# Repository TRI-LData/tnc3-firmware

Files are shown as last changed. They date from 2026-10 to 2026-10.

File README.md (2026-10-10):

# TNC3L
# !!! THIS RESPOSITORY IS WORK INPROGRESS !!!
## Current Status: Repository work and TNC3L prep for FCC testing

TNC3L was developed as an enhanced hardware version of Mobilinkd’s open-sourced TNC3.  
The goal was to make TNC3L easier to use and maintain from a hardware perspective and 
not to change/rewrite firmware developed for TNC3.  This would ensure application compatibility, 
including TNC3 firmware updates.  TNC3L is open-sourced and licensed under GPL-3.0.  This 
repository is a fork of 

 [Mobilinkd TNC3 Repository](https://github.com/mobilinkd/tnc3-firmware)

 TNC3L hardware specific files are in the TNC3L repository directory.  PCB files,
 schematics, BOM, and 3D printer STL files are included.

## TNC3L and TNC3 Differences

TNC3L firmware is almost identical to TNC3 firmware as posted on GitHub.  Minor firmware
changes have been made to accommodate hardware differences.  Functionally all applications 
compatible with the TNC3 should work with the TNC3L.  This repository is for TNC3 firmware
ported to TNC3L hardware.  The code changes are enabled with a define statement
in main.h, #define TNC3L.

TNC3L modified files from TNC3 are:
1) main.h
2) main.c
3) util.h (new)
4) LEDIndicator.cpp
5) IOEventTask.cpp
Search for #ifdef TNC3 in each to view modifications.

TNC3L was designed to be attached to an HT by simply plugging it in.  There are no 
cables or need to attach the device to the HT with rubber bands or Velcro.   Simply plug 
it in or out of the HT’s speaker and mic jacks.  This configuration allows the HT 
to be comfortably handheld, used with a belt clip, or inserted in the charging 
cradle without detaching the TNC3L from the HT.  Power button and status indicators
are visible and accessible from the front of the HT.

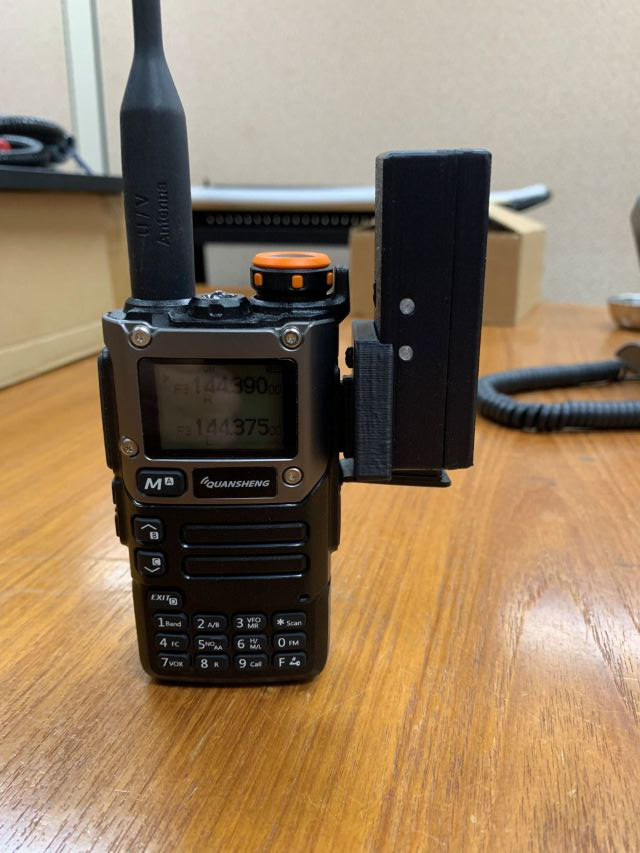
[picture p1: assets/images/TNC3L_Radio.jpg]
TNC3L attached to HT

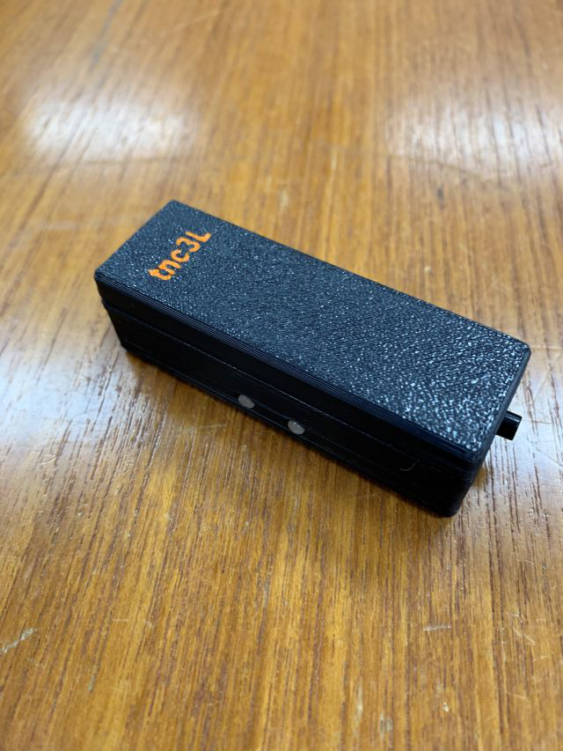
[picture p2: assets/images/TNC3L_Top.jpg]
TNC3L Top

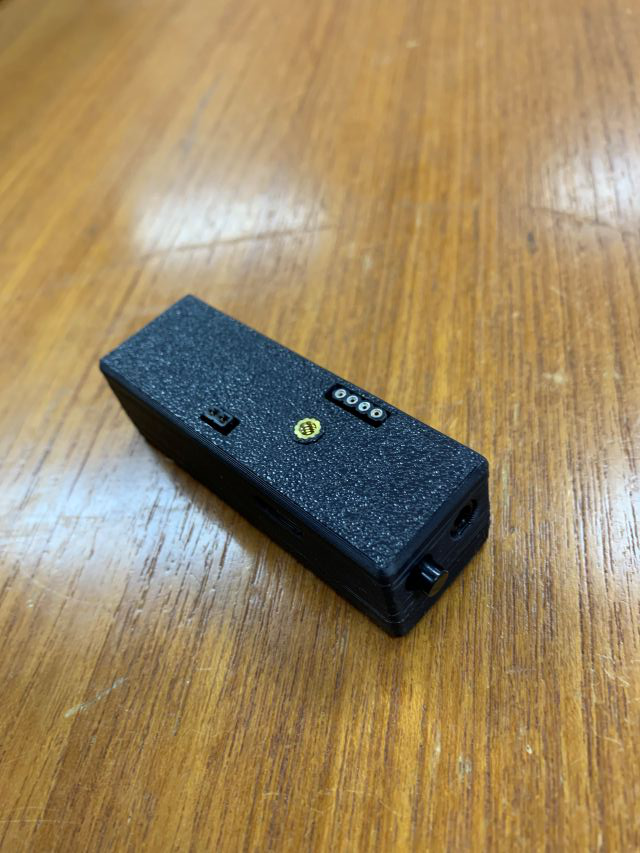
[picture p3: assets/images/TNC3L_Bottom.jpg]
TNC3L Bottom


### Rechargeable/Replaceable Battery
TNC3L uses a standard 14500 lithium Ion 3.7V battery.  Battery protection and
charging are provided on the circuit board.  Discharged batteries can be replaced without tools or 
charged via the USB port.  The TNC3L circuit board can accommodate other batteries 
size with higher capacities.   However, the standard enclosure is designed for 
14500 batteries only.

### Power button
The push button located on the base of the TNC3L is used to power on and off the device.  
In the off position it disconnects the battery from other circuitry.  The MCU, Bluetooth module, 
LEDs, etc. do not consume any power in the off position.  It is a latching push button switch.  
The on or off position is clearly visible.  Powering the device directly with a push button 
eliminated the need for the MCU to be “on” to control power to other devices and to detect 
button presses to turn itself on or off.  This approach maximizes battery life.  
However, minor firmware modifications were needed.

### USB Type C Connector
A type C USB connector is used instead of a micro-USB.  It has the same connectivity as TNC3
and can be used for charging or programming.  Power is always on when the USB is plugged in
irrespective of the push button.

### Status Indicators (LEDs)
Two status indicators are on the TNC3L.  One is the same as TNC3 for radio, Bluetooth status 
and processor status.  The other is for battery charging.  TNC3L has three charging 
states; green for charging complete; red for charging; off if no USB or off if the USB 
is plugged in and there is a charging error.

### DFU MODE PINS
TNC3L uses a two-pin IDC header to place it into DFU mode for programming.  It does not have 
separate reset or DFU buttons.   
1) Power button in the off position
2) Short the IDC header (jumper wire)
3) Attach USB
4) Remove jumper

### Radio to TNC3L Interface
A TRRS 3.5mm jack and a 4 pin IDC header are available to interface the TNC3L to a radio.  
The 3.5mm TRRS jack has the same signals as the TNC3.  Cables compatible with TNC3 should also be 
compatible with TNC3L.  A second MIC/speaker interface was added to the TNC3L using 
a 4-pin IDC connector.  This port can be used for connecting the TNC3L to radios without
using a 3.5mm plug.  TNC3L K1 style docking adapter is an example.  It connects the TNC3L to the HT without a cable.

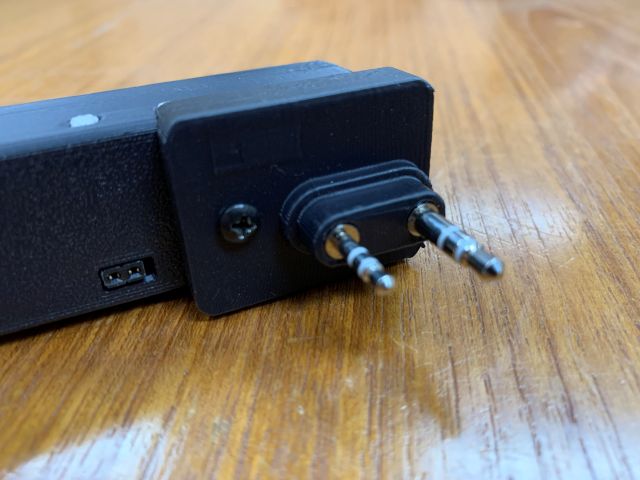
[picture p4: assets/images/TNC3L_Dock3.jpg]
TNC3L DOCK3


### 3D Printed Enclosure
The TNC3L enclosure and docking adapter are made from 3D printed parts.  FCC testing was
also performed using TNC3L as shown here.  TNC3L is not limited to the a specific enclosure.  Users are welcome to 
design custom enclosures to adopt various battery sizes and device orientation. 
 
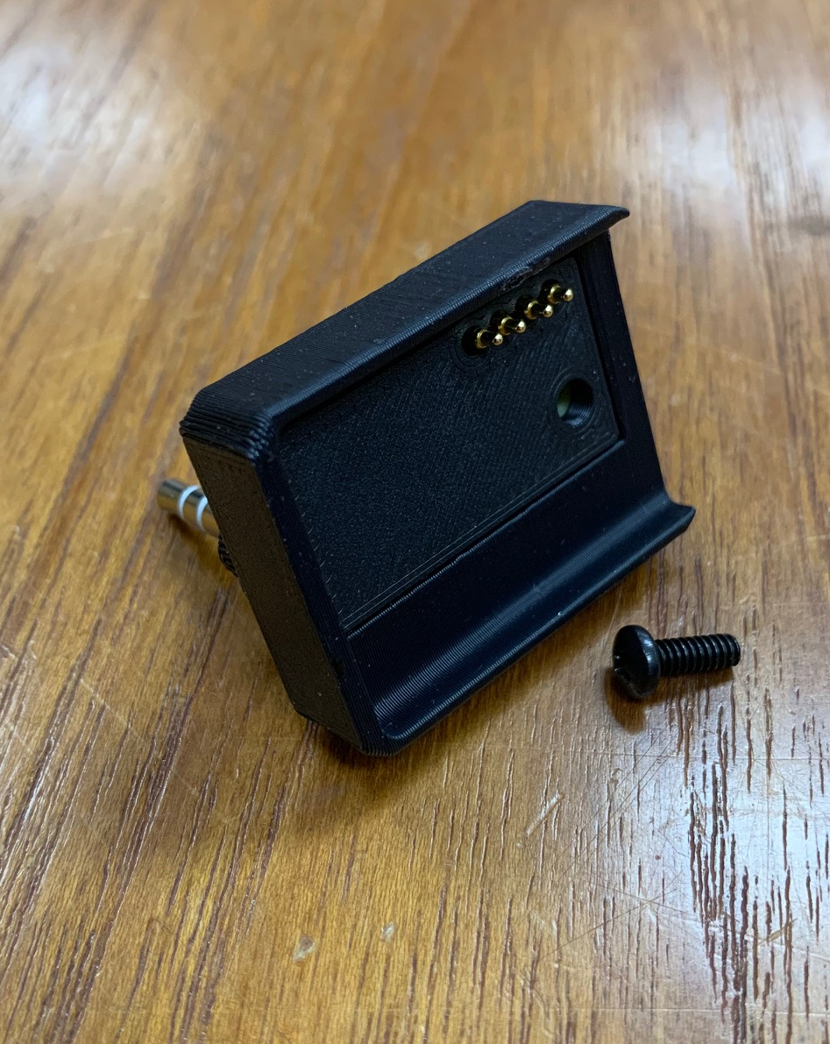
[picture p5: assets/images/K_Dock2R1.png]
K Dock


# Firmware 
Please refer to Mobilinkd's TNC3 GitHub repository for building and installing firmware.  Do not use frimware
directly from their repository, use the firmware source provided in this repository.

 [Mobilinkd TNC3 Repository](https://github.com/mobilinkd/tnc3-firmware)

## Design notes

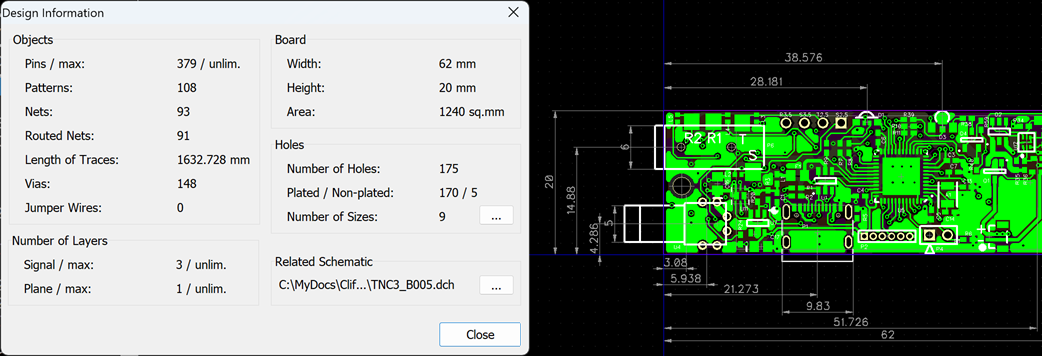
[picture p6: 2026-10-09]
TNC3L_Hardware/TNC3L_Info/TNC3L_B005_Info.png

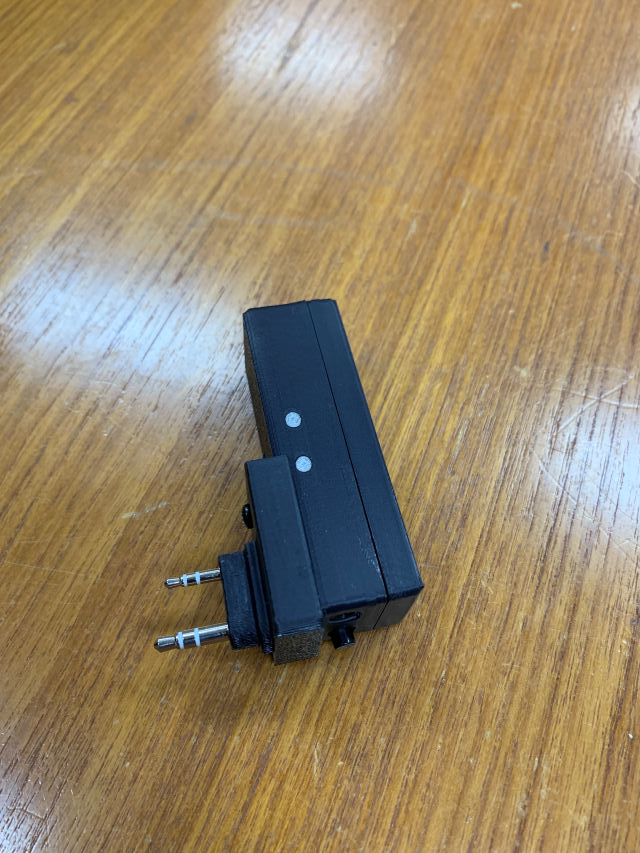
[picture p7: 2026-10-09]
assets/images/TNC3L_Status.jpg

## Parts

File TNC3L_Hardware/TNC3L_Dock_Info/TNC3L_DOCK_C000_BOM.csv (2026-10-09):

# | RefDes | Value | Name | Pattern | Quantity
1 | J1 | 2.5 R | J0806 | J0604 | 1
2 | J2 | 3.5 T | J0806 | J0604 | 1
3 | P1 | IDC1X4 | 6mm Pogo | TNC3_POGO | 1
4 | P2 | 2.5 TR | IDC1X2 | IDC1X2 | 1
5 | P3 | 3.5 SR | IDC1X2 | IDC1X2 | 1
6 | P4 | IDC1X2 | IDC1X2 | IDC1X2 | 1

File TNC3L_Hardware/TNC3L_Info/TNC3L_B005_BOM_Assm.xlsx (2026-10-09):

 | TNC3L_B005_BOM |  |  |  |  |  | NO POP = do not install
Item | RefDes | Value | Name | Pattern | Quantity | Distributor | Comment
1 | A1 | 32.768KHz | ABS07L-32.768KHZ-T | ABS07L | 1 | Digikey
2 | B1 | DF52-2S | DF52-2S-0.8H(21) | DF52-2S | 1 | Digikey
3 | C1, C24, C25 | 4.7uF 10V | CL05A475MP5NRNC | CAP_0402 | 3 | Digikey
4 | C2, C18 | 10nF | GRM155R71C103KA01D | CAP_0402 | 2 | Digikey
5 | C3, C4, C5, C6, C7, C8, C9, C11, C22, C27, C30, C32 | 0.1uF | CL05B104KO5NNNC | CAP_0402 | 12 | Digikey
6 | C10, C20 | 1nF | GRM155R71C102KA01D | CAP_0402 | 2 | Digikey
7 | C12, C21 | 33nF | GRM155R61C333KA01D | CAP_0402 | 2 | Digikey
8 | C13, C14 | 22pF | CC0402JRNPO7BN220 | RES_0402 | 2 | Digikey
9 | C15, C23 | 470pF | CC0402JRNPO7BN471 | CAP_0402 | 2 | Digikey
10 | C16, C17 | 10uF 16V | CL21A106KOCLRNC | CAP_0805 | 2 | Digikey
11 | C19 | 2.2uF | CC0402KRX5R7BB225 | CAP_0402 | 1 | Digikey
12 | C26 | .22uF | CL05B224KO5NNNC | CAP_0402 | 1 | Digikey
13 | C28 | 33uF 6.3V | GMC21X5R336M6R3NT | CAP_0805 | 1 | Digikey
14 | C29 | 1uF 16V | CL05A105KO5NNNC | RES_0402 | 1 | Digikey
15 | C31 | 100pF 16V | C0402C101K4RACAUTO | RES_0402 | 1 | Digikey
16 | D1 | RGB_CA | E3113BGR-10D0003Q3U1930 | LED_RGB_RA_SM | 1 | Digikey
17 | D2 | PMEG2010ER | PMEG2010ER | SOD-123F | 1 | Digikey
18 | D3 | B2592USNG20D0001L2U1930 | LED_RG | LED_RG_B2592USNG20D0001L2U1930 | 1 | Digikey
19 | D4 | BAT54SWT1G | BAT54SWT1G_SOT323 | SOT323 | 1 | Digikey
20 | D5 | 4.3V Zener | BZT52C4V3LP-7 | DIO_0402 | 1 | Digikey
21 | F1 | 750mA | PTS08056V075 | RES_0805 | 1 | Digikey
22 | L1 | FB 600R@100Mhz | BLM15AX601SN1D | RES_0402 | 1 | Digikey
23 | L2, L3, L4, L5 | BLM15AG102SN1D | BLM15AG102SN1D | IND_0402 | 4 | Digikey
24 | L6 | MU1608-221Y | MU1608-221Y | IND_0603 | 1 | Digikey
25 | P1 | USB-C | USB4105-GF-A | USB4105_GCT | 1 | Digikey
26 | P2 | IDC1X6 | IDC1x6 | IDC1X6_05 | 1 |  | NO POP
27 | P3 | IDC1X4 | IDC1X4_05 | IDC1X4_Socket | 1 |  | NO POP
28 | P4 | IDC1X2 | IDC1X2 | IDC1X2 | 1 |  | NO POP
29 | P6 | TRRS 3.5 | SJ2-3574A-SMT-TR | SJ2-3574A-SMT-TR | 1 | Digikey
30 | Q1 | DMP3099L-7 | MOSFET-P | SOT23 | 1 | Mouser
31 | Q2 | FS8205A | FS8205A-SOT23-6 | SOT23-6 | 1 | Digikey
32 | Q4 | MMBT2222A | NPN | SOT23 | 1 | Digikey
33 | R1, R38, R39, R41 | 1.5K | 1.5K | RES_0402 | 4 | Digikey | Generic, 1%, 1/10 W or better
34 | R2, R5 | 5.1K | 5.1K | RES_0402 | 2 | Digikey | Generic, 1%, 1/10 W or better
35 | R3, R13, R28 | 30K | 30K | RES_0402 | 3 | Digikey | Generic, 1%, 1/10 W or better
36 | R4 | 0 | 0 | RES_0402 | 1 | Digikey | Generic, 1%, 1/10 W or better
37 | R6, R20, R32 | 10K | 10K | RES_0402 | 3 | Digikey | Generic, 1%, 1/10 W or better
38 | R7, R8, R9 | 220 | 2.2K | RES_0402 | 3 | Digikey | Generic, 1%, 1/10 W or better
39 | R10, R11, R24 | 4.7K | 4.7K | RES_0402 | 3 | Digikey | Generic, 1%, 1/10 W or better
40 | R12, R30, R31 | 2.2K | 2.2K | RES_0402 | 3 | Digikey | Generic, 1%, 1/10 W or better
41 | R14, R26 | 16K | 16K | RES_0402 | 2 | Digikey | Generic, 1%, 1/10 W or better
42 | R15, R17 | 220 | 220 | RES_0402 | 2 | Digikey | Generic, 1%, 1/10 W or better
43 | R16, R19, R25 | 100K | 100K | RES_0402 | 3 | Digikey | Generic, 1%, 1/10 W or better
44 | R18, R23 | 510 | 510 | RES_0402 | 2 | Digikey | Generic, 1%, 1/10 W or better
45 | R21, R22 | 470 | 470 | RES_0402 | 2 | Digikey | Generic, 1%, 1/10 W or better
46 | R27 | 6.8K | 6.8K | RES_0402 | 1 | Digikey | Generic, 1%, 1/10 W or better
47 | R29 | 100 | 100 | RES_0402 | 1 | Digikey | Generic, 1%, 1/10 W or better
48 | R33 | 0 | RC0603JR-070RL | RES_0603 | 1 | Digikey | Generic, 1%, 1/10 W or better
49 | R34 | 2K | 2k | RES_0402 | 1 | Digikey | Generic, 1%, 1/10 W or better
50 | R35 | 20 | 20 | RES_0402 | 1 | Digikey | Generic, 1%, 1/10 W or better
51 | R36 | 300 | 300 | RES_0402 | 1 | Digikey | Generic, 1%, 1/10 W or better
52 | R37 | 10mOhm | 10mOhm | RES_0402 | 1 | Digikey | Generic, 1%, 1/10 W or better
53 | R40 | 7.23K | 7.23K | RES_0402 | 1 | Digikey | Generic, 1%, 1/10 W or better
54 | R59 | 10K | 0 | RES_0402 | 1 | Digikey | Generic, 1%, 1/10 W or better
55 | T5 | TP | TP | TP05 | 1 |  | NO POP
56 | U1 | USBLC6-2SC6 | USB_TVS-SOT23-6 | SOT23-6 | 1 | Digikey
57 | U2 | BM78SPPS5NC2-000 | BM78SPPS5NC2-000 | MOD33_BM78SPPS5M | 1 | Digikey
58 | U3 | DUAL_N_N | SIA918EDJ-T1-GE3 | SON_SIA921EDJ_VI | 1 | Digikey
59 | U4 | ZGSZJHF | PB_Latch_SPDT | PB_SPDT_LATCH | 1 | Amazon | NO POP
60 | U5 | STM32L433CCU6 | STM32L433CCU6-48QFN | QFN-48/7x7x0.5 | 1 | Digikey
61 | U6, U8 | MCP6002T-IMS-8MSOP | MCP6002T-IMS | MSOP8_MC_MCH | 2 | Digikey
62 | U7 | XC6210-3.3V | XC6210B332MR-G | SOT23-5 | 1 | Digikey
63 | U9 | MCP73831T-2ACI/OT | MCP73831 | SOT23-5 | 1 | Digikey
64 | U10 | M24C32-FDW6TP | M24C32-FDW6TP | TSSOP8_4P5X3P1X0 | 1 | Digikey
65 | U11 | DUAL_N_P | SIA519EDJ-T1-GE3 | SON_SIA921EDJ_VI | 1 | Digikey
66 | U12 | BQ298215RUGR | BQ298215RUGR | X2QFN_6 | 1 | Digikey
 |  |  |  |  | 109

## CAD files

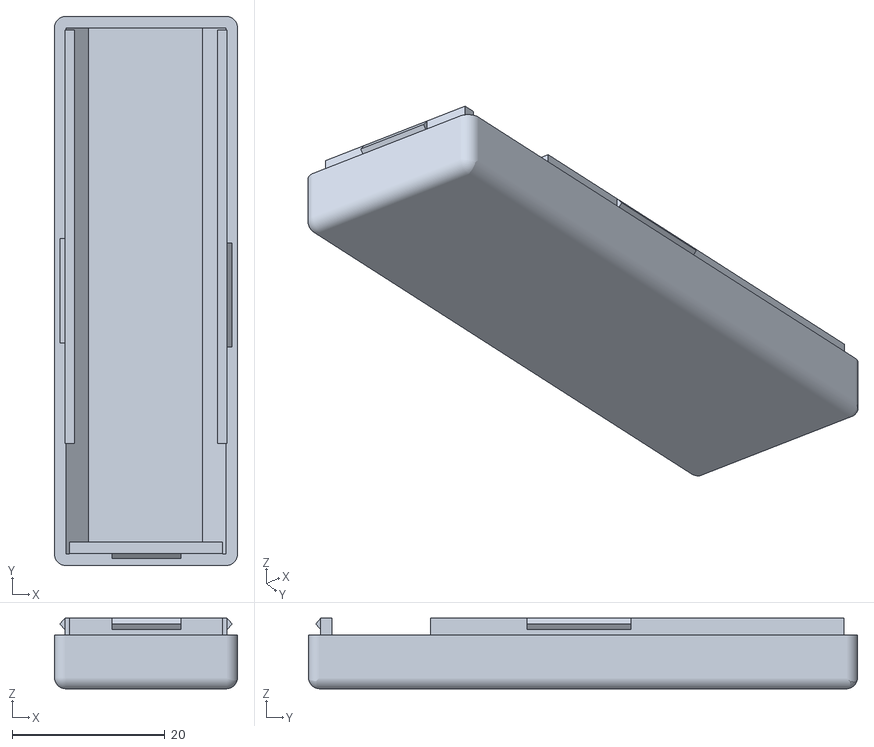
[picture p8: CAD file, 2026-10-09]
TNC3L_Hardware/TNC3L_3D/TNC3L2_02_Cover.stl
24.0 x 72.0 x 9.25

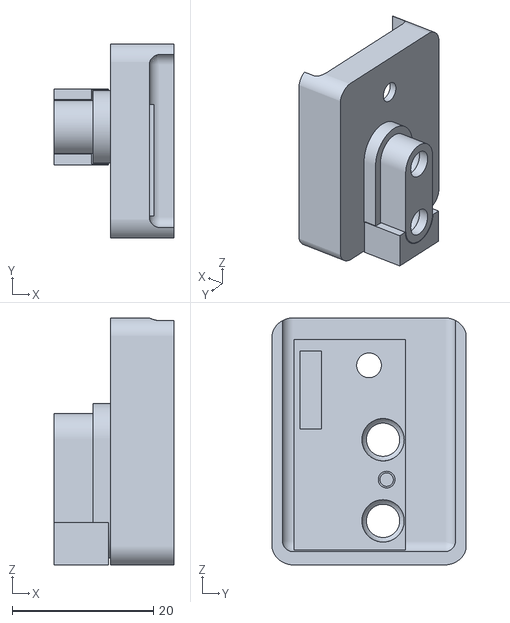
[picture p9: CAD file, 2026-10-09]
TNC3L_Hardware/TNC3L_Dock_3D/TNC3L_Dock_11_Base.stl
17.0 x 27.5 x 35.0

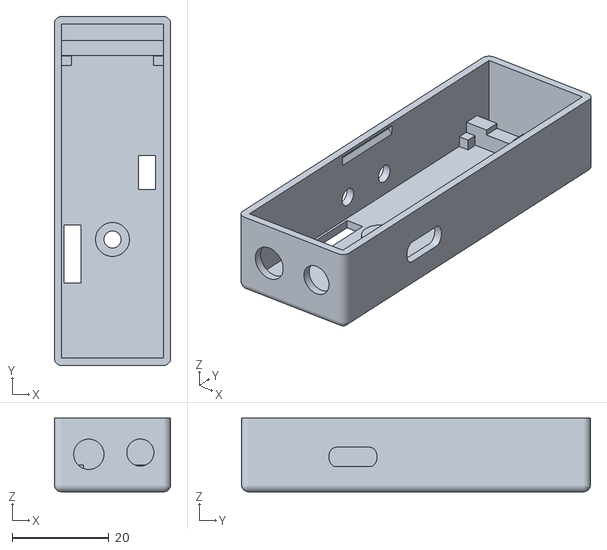
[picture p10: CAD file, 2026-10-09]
TNC3L_Hardware/TNC3L_3D/TNC3L2_02_Base.stl
24.0 x 72.0 x 15.2

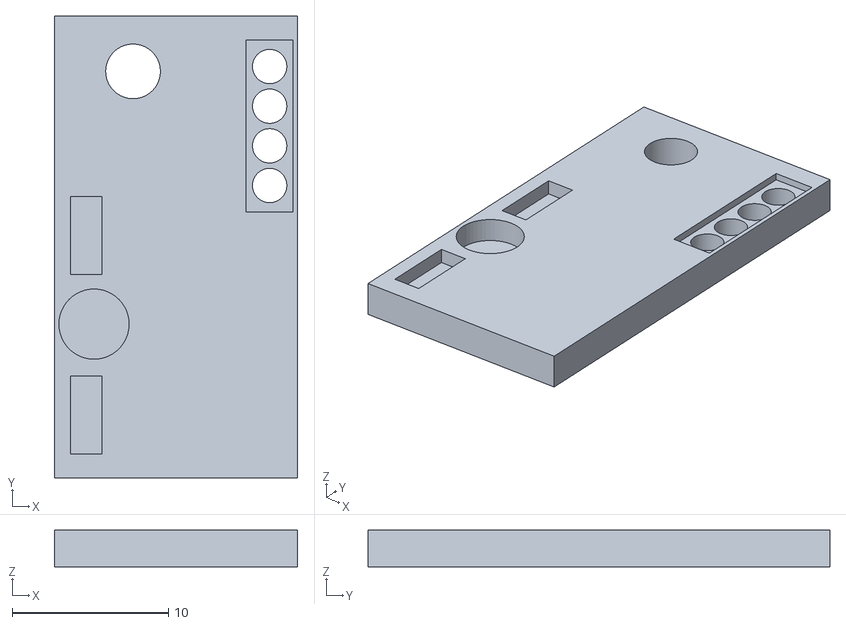
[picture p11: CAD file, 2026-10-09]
TNC3L_Hardware/TNC3L_Dock_3D/TNC3L_Dock_11_Cover.stl
15.6 x 29.6 x 2.35

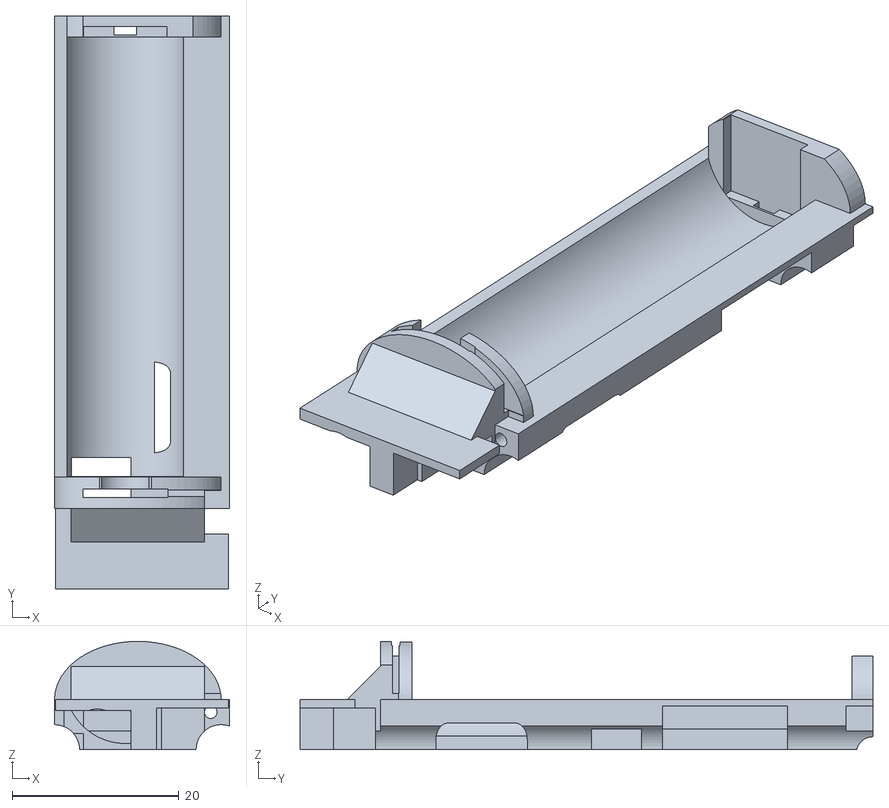
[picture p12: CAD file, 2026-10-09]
TNC3L_Hardware/TNC3L_3D/TNC3L2_02_Bat.stl
21.0 x 68.8 x 13.0

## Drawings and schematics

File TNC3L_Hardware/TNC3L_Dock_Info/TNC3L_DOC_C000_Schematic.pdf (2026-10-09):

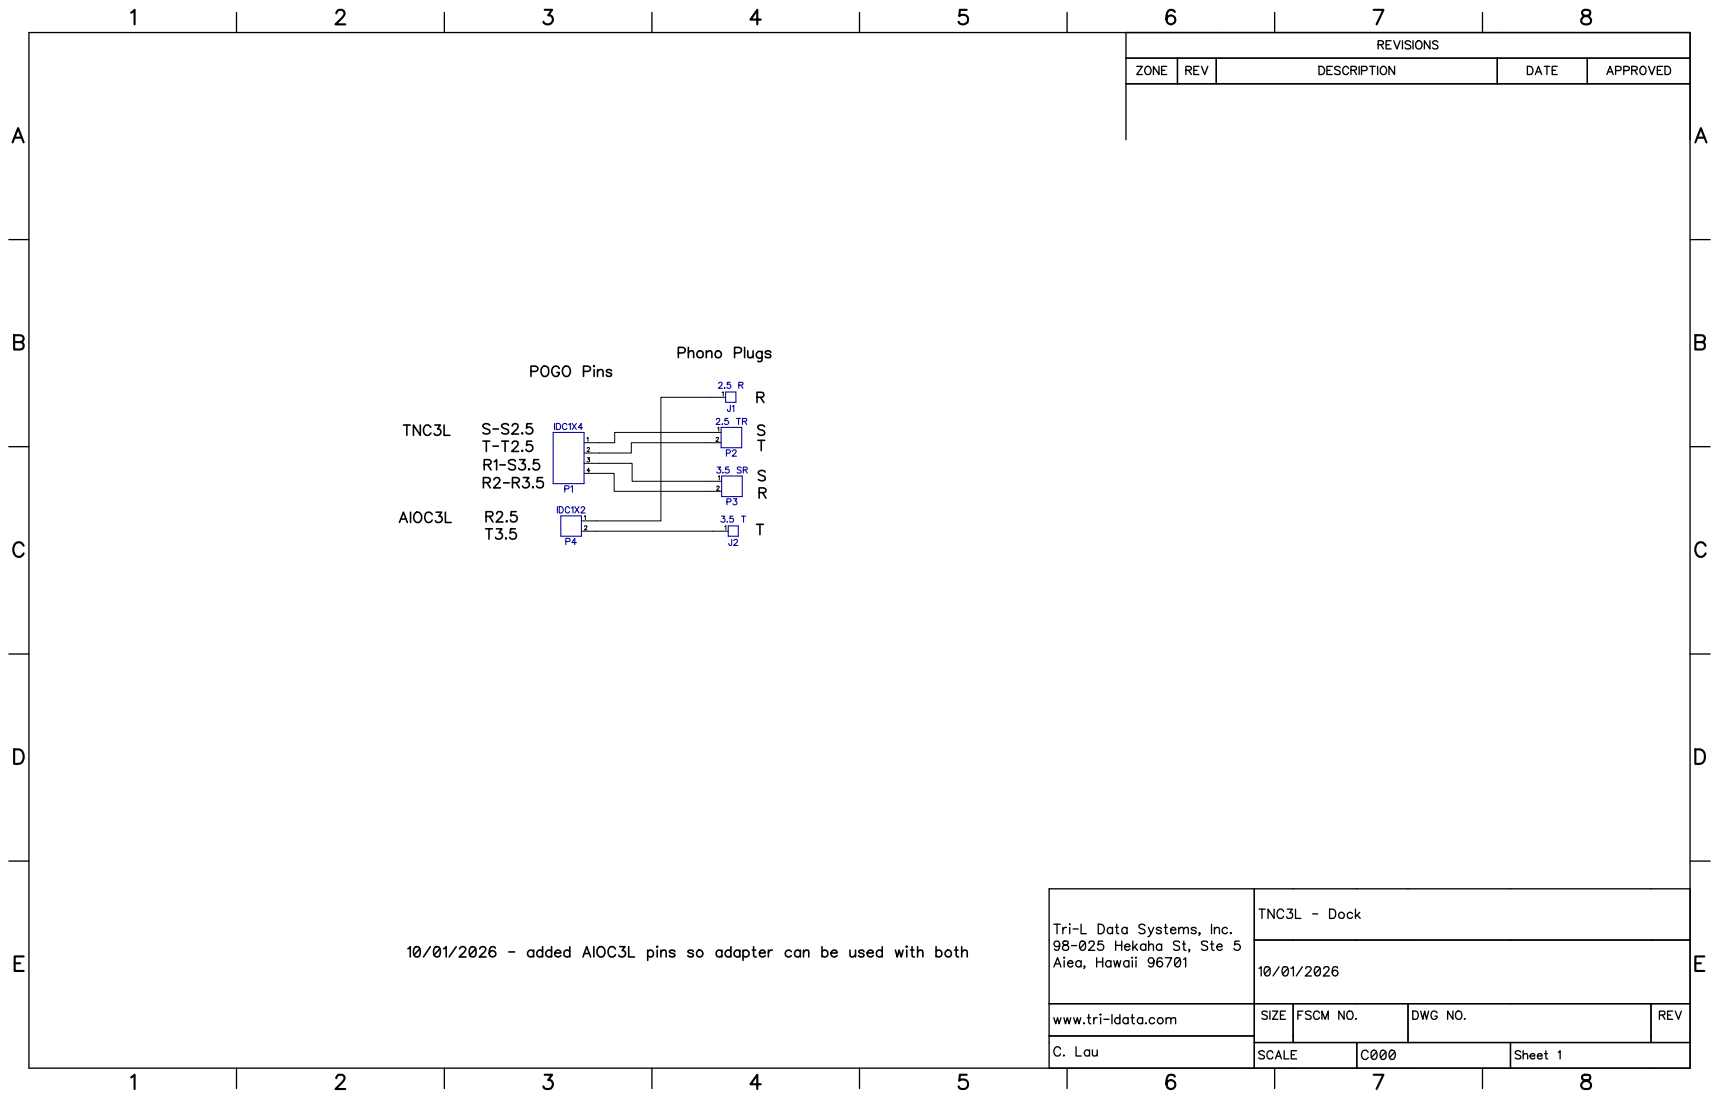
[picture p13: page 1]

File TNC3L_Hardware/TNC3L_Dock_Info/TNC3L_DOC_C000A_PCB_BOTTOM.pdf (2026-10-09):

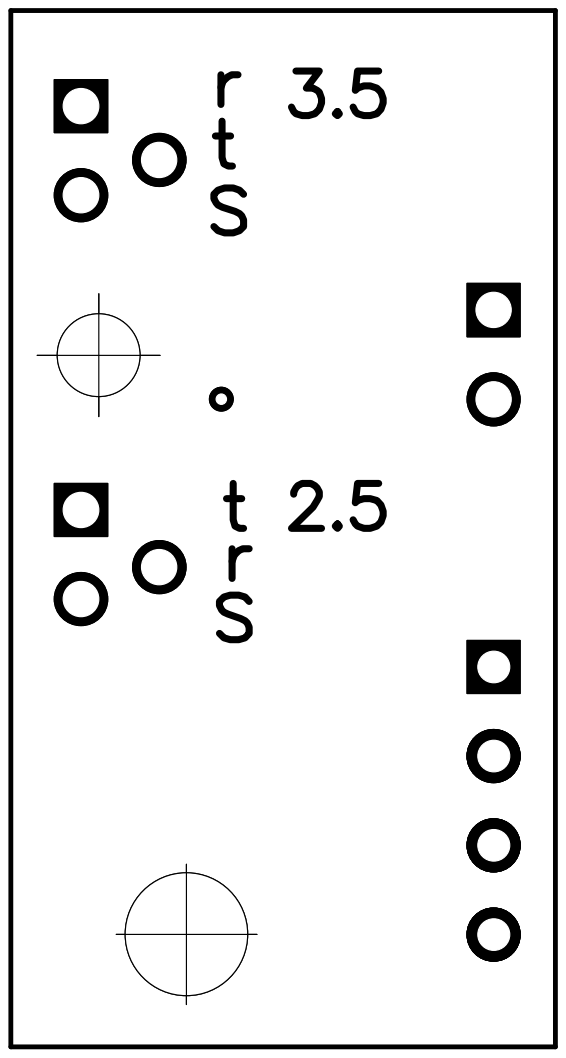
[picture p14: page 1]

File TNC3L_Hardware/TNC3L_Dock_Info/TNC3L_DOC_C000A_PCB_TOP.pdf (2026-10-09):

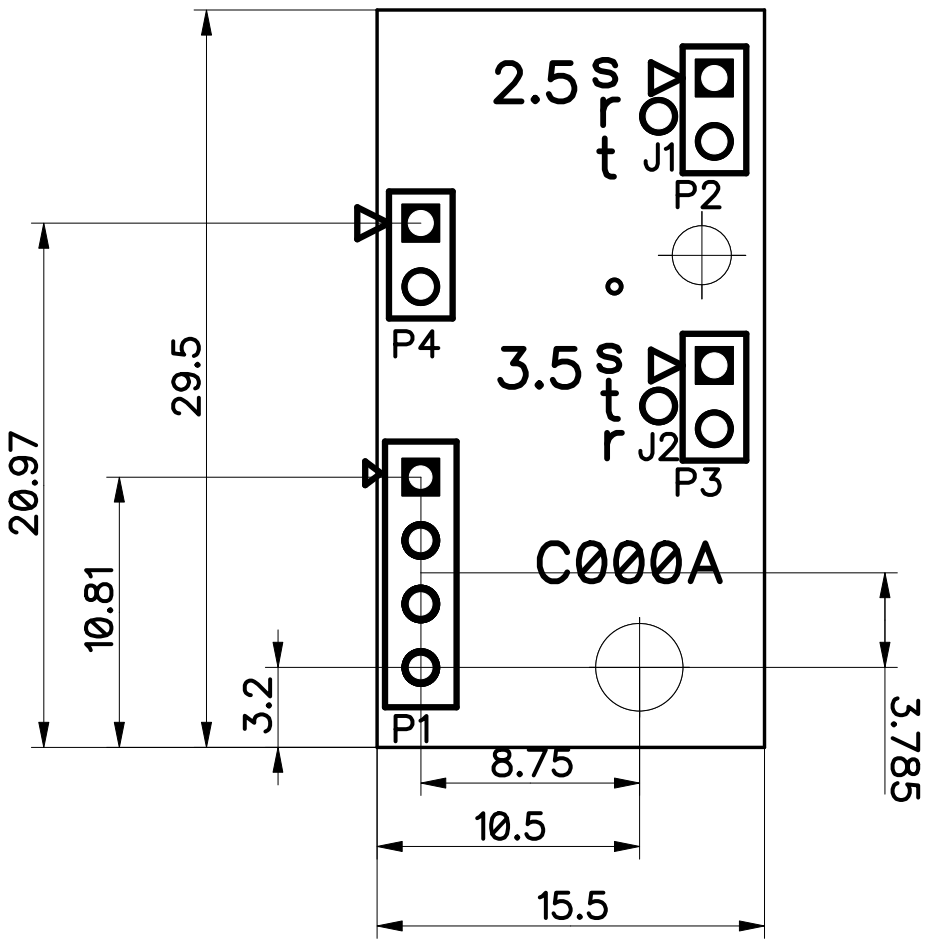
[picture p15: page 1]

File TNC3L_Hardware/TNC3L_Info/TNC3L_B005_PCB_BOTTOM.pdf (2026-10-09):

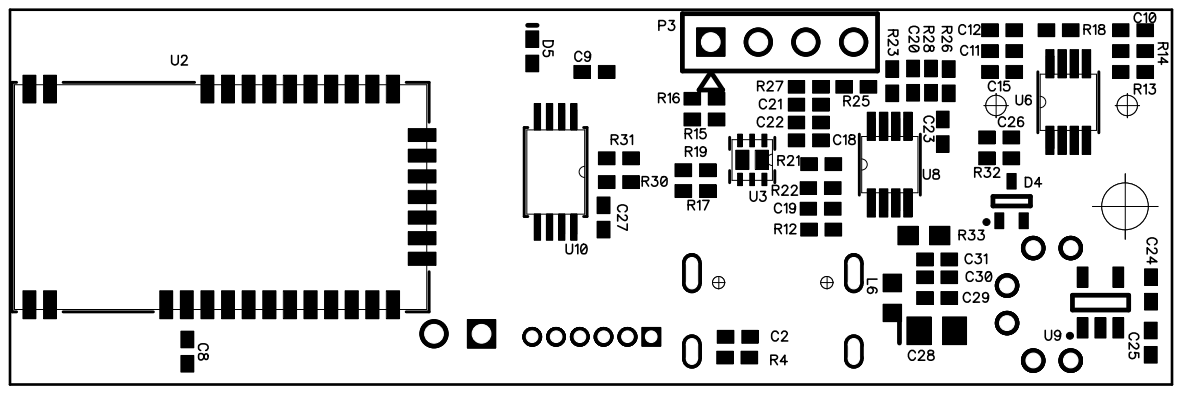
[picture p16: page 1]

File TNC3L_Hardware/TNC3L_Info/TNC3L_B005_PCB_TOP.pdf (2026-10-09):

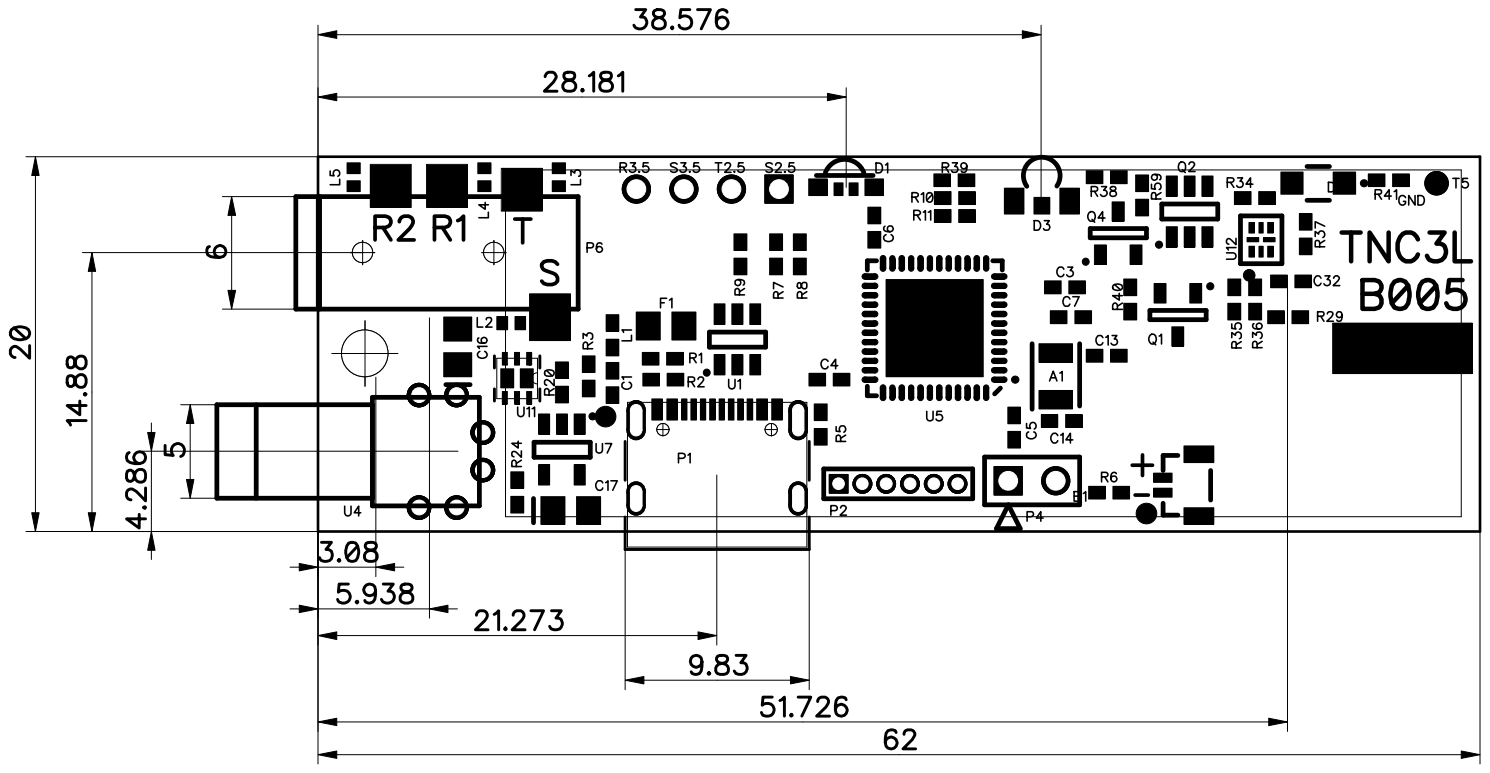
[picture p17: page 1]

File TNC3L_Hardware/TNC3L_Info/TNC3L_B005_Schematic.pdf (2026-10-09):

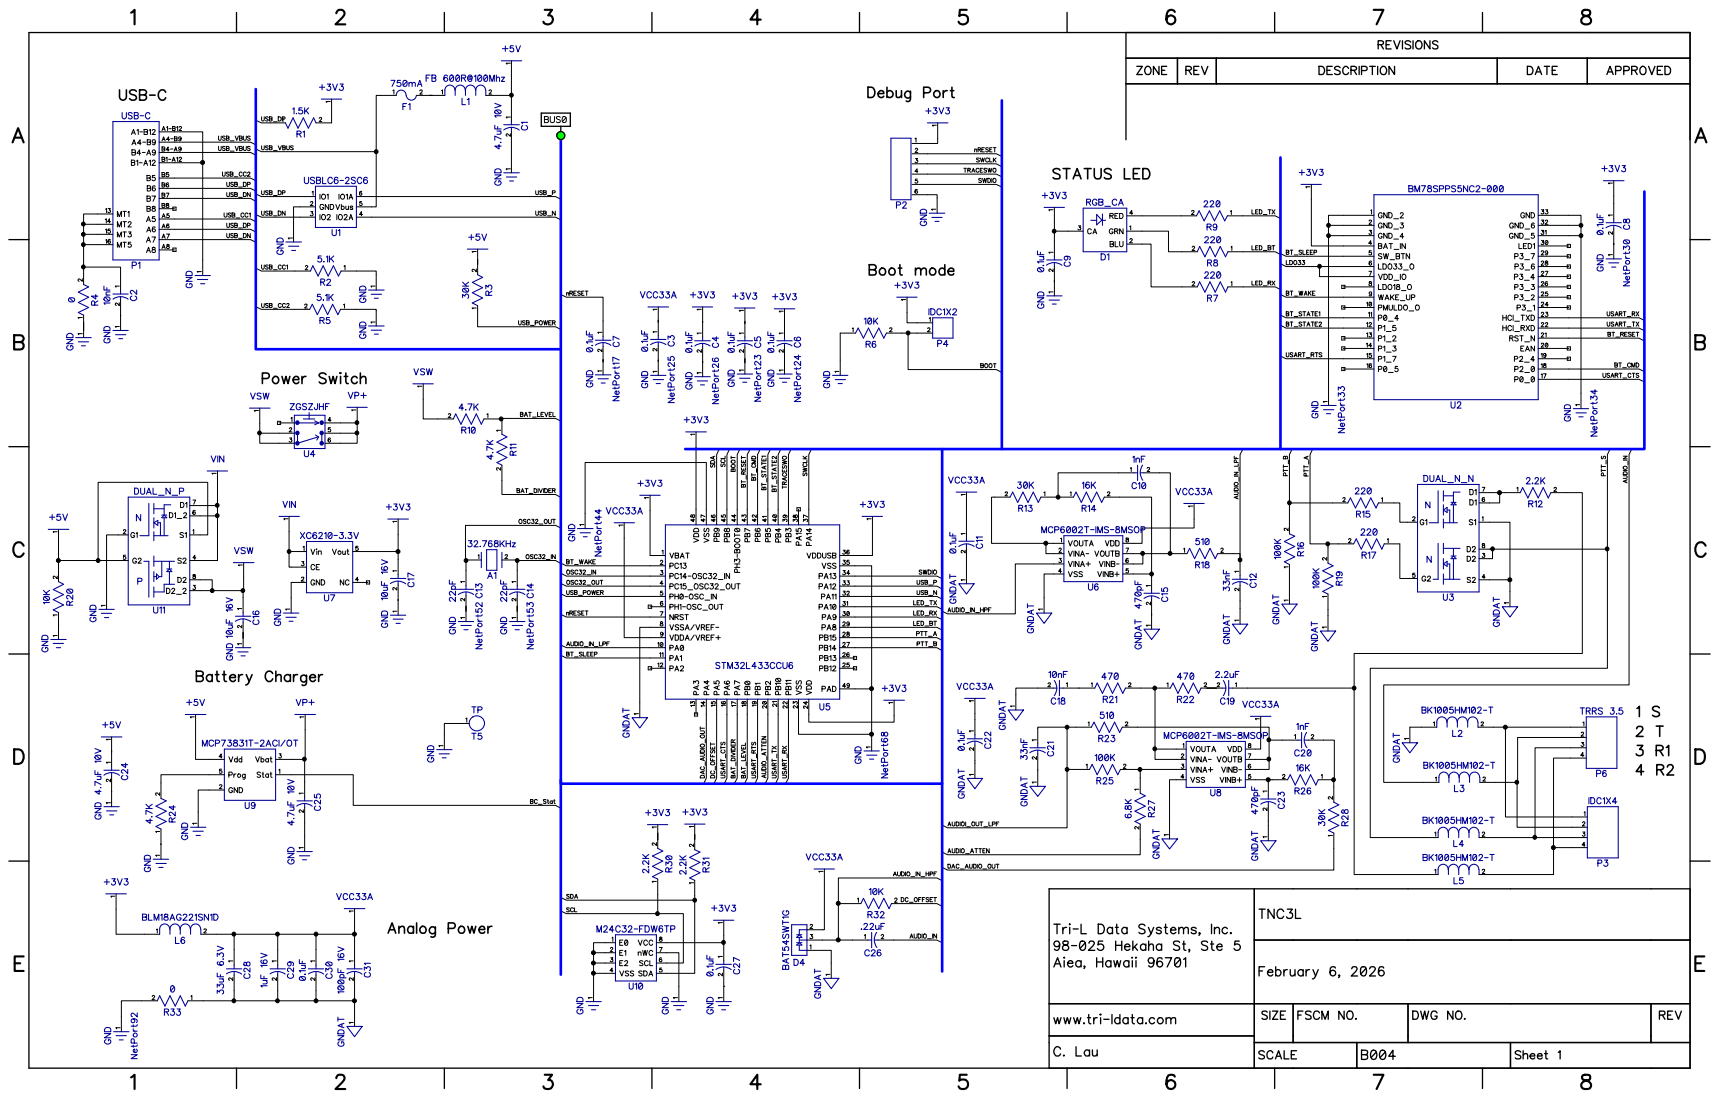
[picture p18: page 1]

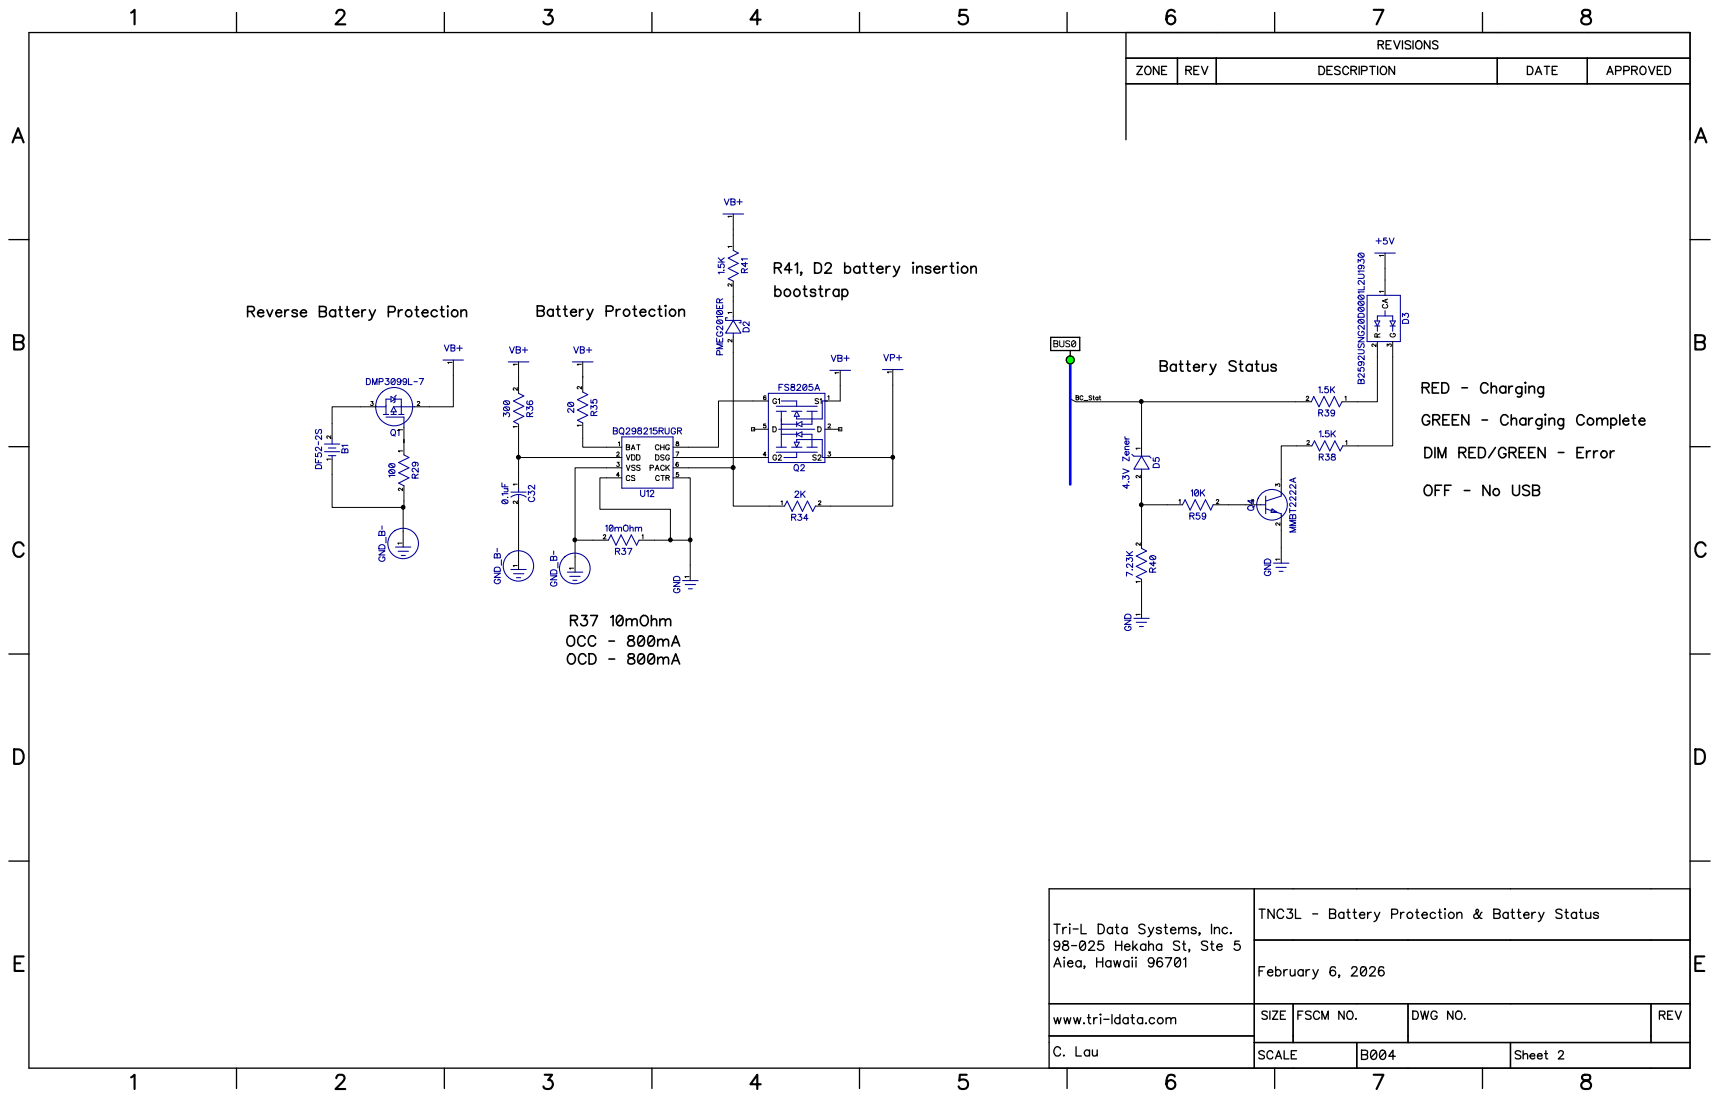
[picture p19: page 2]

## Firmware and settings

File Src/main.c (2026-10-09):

/**
  ******************************************************************************
  * @file           : main.c
  * @brief          : Main program body
  ******************************************************************************
  * This notice applies to any and all portions of this file
  * that are not between comment pairs USER CODE BEGIN and
  * USER CODE END. Other portions of this file, whether 
  * inserted by the user or by software development tools
  * are owned by their respective copyright owners.
  *
  * Copyright (c) 2018 STMicroelectronics International N.V. 
  * All rights reserved.
  *
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
  ******************************************************************************
  */
/* Includes ------------------------------------------------------------------*/
#include "main.h"
#include "stm32l4xx_hal.h"
#include "cmsis_os.h"
#include "usb_device.h"

/* USER CODE BEGIN Includes */
#include "usbd_core.h"
#include "IOEventTask.h"
#include "PortInterface.h"
#include "LEDIndicator.h"
#include "bm78.h"
#include "KissHardware.h"
#include "Log.h"

/* USER CODE END Includes */

ADC_HandleTypeDef hadc1;
DMA_HandleTypeDef hdma_adc1;

CRC_HandleTypeDef hcrc;

DAC_HandleTypeDef hdac1;
DMA_HandleTypeDef hdma_dac_ch1;

I2C_HandleTypeDef hi2c1;
DMA_HandleTypeDef hdma_i2c1_tx;
DMA_HandleTypeDef hdma_i2c1_rx;

IWDG_HandleTypeDef hiwdg;

OPAMP_HandleTypeDef hopamp1;

RNG_HandleTypeDef hrng;

RTC_HandleTypeDef hrtc;

TIM_HandleTypeDef htim1;
TIM_HandleTypeDef htim6;
TIM_HandleTypeDef htim7;

UART_HandleTypeDef huart3;
DMA_HandleTypeDef hdma_usart3_tx;
DMA_HandleTypeDef hdma_usart3_rx;

osThreadId defaultTaskHandle;
uint32_t defaultTaskBuffer[ 256 ];
osStaticThreadDef_t defaultTaskControlBlock;
osThreadId ioEventTaskHandle;
uint32_t ioEventTaskBuffer[ 384 ];
osStaticThreadDef_t ioEventTaskControlBlock;
osThreadId audioInputTaskHandle;
uint32_t audioInputTaskBuffer[ 512 ];
osStaticThreadDef_t audioInputTaskControlBlock;
osThreadId modulatorTaskHandle;
uint32_t modulatorTaskBuffer[ 384 ];
osStaticThreadDef_t modulatorTaskControlBlock;
osMessageQId ioEventQueueHandle;
uint8_t ioEventQueueBuffer[ 16 * sizeof( uint32_t ) ];
osStaticMessageQDef_t ioEventQueueControlBlock;
osMessageQId serialInputQueueHandle;
uint8_t serialInputQueueBuffer[ 16 * sizeof( uint32_t ) ];
osStaticMessageQDef_t serialInputQueueControlBlock;
osMessageQId serialOutputQueueHandle;
uint8_t serialOutputQueueBuffer[ 16 * sizeof( uint32_t ) ];
osStaticMessageQDef_t serialOutputQueueControlBlock;
osMessageQId audioInputQueueHandle;
uint8_t audioInputQueueBuffer[ 8 * sizeof( uint32_t ) ];
osStaticMessageQDef_t audioInputQueueControlBlock;
osMessageQId hdlcInputQueueHandle;
uint8_t hdlcInputQueueBuffer[ 3 * sizeof( uint32_t ) ];
osStaticMessageQDef_t hdlcInputQueueControlBlock;
osMessageQId hdlcOutputQueueHandle;
uint8_t hdlcOutputQueueBuffer[ 8 * sizeof( uint32_t ) ];
osStaticMessageQDef_t hdlcOutputQueueControlBlock;
osMessageQId dacOutputQueueHandle;
uint8_t dacOutputQueueBuffer[ 128 * sizeof( uint8_t ) ];
osStaticMessageQDef_t dacOutputQueueControlBlock;
osMessageQId adcInputQueueHandle;
uint8_t adcInputQueueBuffer[ 8 * sizeof( uint32_t ) ];
osStaticMessageQDef_t adcInputQueueControlBlock;
osTimerId beaconTimer1Handle;
osStaticTimerDef_t beaconTimer1ControlBlock;
osTimerId beaconTimer2Handle;
osStaticTimerDef_t beaconTimer2ControlBlock;
osTimerId beaconTimer3Handle;
osStaticTimerDef_t beaconTimer3ControlBlock;
osTimerId beaconTimer4Handle;
osStaticTimerDef_t beaconTimer4ControlBlock;
osTimerId usbShutdownTimerHandle;
osStaticTimerDef_t usbShutdownTimerControlBlock;

/* USER CODE BEGIN PV */
osMutexId hardwareInitMutexHandle;

int lost_power = 0;
int reset_requested = 0;
char serial_number_64[13] = {0};
// Make sure it is not overwritten during resets (bss3).
uint8_t mac_address[6] __attribute__((section(".bss3"))) = {0};
char error_message[80] __attribute__((section(".bss3"))) = {0};
// USB power control -- need to renegotiate USB charging in STOP mode.
int go_back_to_sleep __attribute__((section(".bss3")));
int stop_now __attribute__((section(".bss3")));
int charging_enabled __attribute__((section(".bss3")));
int usb_wake_state __attribute__((section(".bss3")));
int reset_button = 0;

/* USER CODE END PV */

void SystemClock_Config(void);
static void MX_GPIO_Init(void);
static void MX_DMA_Init(void);
static void MX_RTC_Init(void);
static void MX_USART3_UART_Init(void);
static void MX_DAC1_Init(void);
static void MX_ADC1_Init(void);
static void MX_CRC_Init(void);
static void MX_I2C1_Init(void);
static void MX_TIM6_Init(void);
static void MX_TIM7_Init(void);
static void MX_RNG_Init(void);
static void MX_IWDG_Init(void);
static void MX_TIM1_Init(void);
static void MX_OPAMP1_Init(void);
void StartDefaultTask(void const * argument);
extern void startIOEventTask(void const * argument);
extern void startAudioInputTask(void const * argument);
extern void startModulatorTask(void const * argument);
extern void beacon(void const * argument);
extern void shutdown(void const * argument);
void encode_serial_number(void);

void HAL_TIM_MspPostInit(TIM_HandleTypeDef *htim);
                                

/* USER CODE BEGIN PFP */
void stop2(void) __attribute__((noinline));
void configure_gpio_for_stop(void) __attribute__((noinline));
void power_down_vdd(void);
void power_up_vdd(void);
void configure_wakeup_gpio(void);
void enable_debug_gpio(void);
void init_rtc_date_time(void);
void init_rtc_alarm(void);

/* USER CODE END PFP */

/* USER CODE BEGIN 0 */

extern PCD_HandleTypeDef hpcd_USB_FS;


void configure_gpio_for_stop()
{
    __HAL_RCC_GPIOC_CLK_ENABLE();
    __HAL_RCC_GPIOH_CLK_ENABLE();
    __HAL_RCC_GPIOA_CLK_ENABLE();
    __HAL_RCC_GPIOB_CLK_ENABLE();

    HAL_NVIC_DisableIRQ(EXTI3_IRQn);

    // BT_STATE1
    HAL_GPIO_DeInit(BT_STATE1_GPIO_Port, BT_STATE1_Pin);
    HAL_NVIC_DisableIRQ(BT_STATE1_EXTI_IRQn);
    HAL_NVIC_ClearPendingIRQ(BT_STATE1_EXTI_IRQn);

    // BT_STATE2
    HAL_GPIO_DeInit(BT_STATE2_GPIO_Port, BT_STATE2_Pin);
    HAL_NVIC_DisableIRQ(BT_STATE2_EXTI_IRQn);
    HAL_NVIC_ClearPendingIRQ(BT_STATE2_EXTI_IRQn);

    // SW_BOOT
    HAL_GPIO_DeInit(SW_BOOT_GPIO_Port, SW_BOOT_Pin);
    HAL_NVIC_DisableIRQ(SW_BOOT_EXTI_IRQn);
    HAL_NVIC_ClearPendingIRQ(SW_BOOT_EXTI_IRQn);

    // LEDs
    HAL_GPIO_DeInit(GPIOA, LED_BT_Pin|LED_TX_Pin|LED_RX_Pin);

    // I2C
    HAL_GPIO_DeInit(GPIOB, GPIO_PIN_8|GPIO_PIN_9);

    // USB
    HAL_GPIO_DeInit(GPIOA, GPIO_PIN_11|GPIO_PIN_12);

    // UART
    HAL_GPIO_DeInit(GPIOB, GPIO_PIN_1|GPIO_PIN_10|GPIO_PIN_11);
    HAL_GPIO_DeInit(GPIOA, GPIO_PIN_6);

    // Battery level circuit.
    HAL_GPIO_DeInit(BAT_LEVEL_GPIO_Port, BAT_LEVEL_Pin);
    HAL_GPIO_DeInit(BAT_DIVIDER_GPIO_Port, BAT_DIVIDER_Pin);

    if (charging_enabled)
    {
        HAL_GPIO_WritePin(GPIOB, USB_CE_Pin, GPIO_PIN_RESET);
    }
    else
    {
        HAL_GPIO_DeInit(USB_CE_GPIO_Port, USB_CE_Pin);  // Hi-Z
    }

    // Bluetooth module
    HAL_GPIO_DeInit(GPIOC, BT_WAKE_Pin);
    HAL_GPIO_DeInit(GPIOB, BT_RESET_Pin|BT_CMD_Pin);
    HAL_GPIO_WritePin(BT_SLEEP_GPIO_Port, BT_SLEEP_Pin, GPIO_PIN_RESET);
    HAL_Delay(250);

    // Analog pins
    HAL_GPIO_DeInit(GPIOA, AUDIO_IN_Pin|AUDIO_IN_AMP_Pin|DAC_AUDIO_OUT_Pin|DC_OFFSET_Pin);
    HAL_GPIO_DeInit(GPIOB, AUDIO_ATTEN_Pin);

    // PTT pins
    HAL_GPIO_DeInit(GPIOB, PTT_A_Pin|PTT_B_Pin);
}

void power_down_vdd()
{
    __HAL_RCC_GPIOB_CLK_ENABLE();

    HAL_GPIO_WritePin(VDD_EN_GPIO_Port, VDD_EN_Pin, GPIO_PIN_RESET);
    for (int i = 0; i < 4800; ++i) asm volatile("nop");
}

void power_up_vdd()
{
    GPIO_InitTypeDef GPIO_InitStruct;

    __HAL_RCC_GPIOB_CLK_ENABLE();

    GPIO_InitStruct.Pin = VDD_EN_Pin;
    GPIO_InitStruct.Mode = GPIO_MODE_OUTPUT_PP;
    GPIO_InitStruct.Pull = GPIO_PULLUP;
    HAL_GPIO_Init(VDD_EN_GPIO_Port, &GPIO_InitStruct);

    HAL_GPIO_WritePin(VDD_EN_GPIO_Port, VDD_EN_Pin, GPIO_PIN_SET);
}

void configure_wakeup_gpio()
{
    if (!__HAL_RCC_GPIOH_IS_CLK_ENABLED()) Error_Handler();

    GPIO_InitTypeDef GPIO_InitStruct;

    // Reset wakeup pins
    HAL_NVIC_DisableIRQ(EXTI0_IRQn);
    HAL_NVIC_DisableIRQ(EXTI1_IRQn);
#ifndef TNC3L
    HAL_GPIO_DeInit(GPIOH, USB_POWER_Pin|SW_POWER_Pin);
#endif

    // Wake up whenever there is a change in VUSB to handle connect/disconnect events.
    GPIO_InitStruct.Pin = USB_POWER_Pin;
    GPIO_InitStruct.Mode = GPIO_MODE_EVT_RISING_FALLING;
    GPIO_InitStruct.Pull = GPIO_PULLDOWN;   // needed to act as a voltage divider
    HAL_GPIO_Init(GPIOH, &GPIO_InitStruct);

    // Only wake up after the button has been released.  This avoids the case
    // where the TNC is woken up on button down and then immediately put back
    // to sleep when the BUTTON_UP interrupt is received.
    GPIO_InitStruct.Pin = SW_POWER_Pin;
    GPIO_InitStruct.Mode = GPIO_MODE_EVT_FALLING;
    GPIO_InitStruct.Pull = GPIO_NOPULL;
    HAL_GPIO_Init(GPIOH, &GPIO_InitStruct);
}

void enable_debug_gpio()
{
    if (!__HAL_RCC_GPIOA_IS_CLK_ENABLED()) Error_Handler();
    if (!__HAL_RCC_GPIOB_IS_CLK_ENABLED()) Error_Handler();

    GPIO_InitTypeDef GPIO_InitStruct;

    // DEBUG PINS
    GPIO_InitStruct.Pin = GPIO_PIN_13|GPIO_PIN_14;
    GPIO_InitStruct.Mode = GPIO_MODE_AF_PP;
    GPIO_InitStruct.Alternate = GPIO_AF0_SWJ;
    GPIO_InitStruct.Pull = GPIO_NOPULL;
    HAL_GPIO_Init(GPIOA, &GPIO_InitStruct);
    // USART CTS is connected to a device on VDD
    GPIO_InitStruct.Pin = GPIO_PIN_3;
    GPIO_InitStruct.Mode = GPIO_MODE_AF_PP;
    GPIO_InitStruct.Alternate = GPIO_AF0_TRACE;
    GPIO_InitStruct.Pull = GPIO_PULLDOWN;
    HAL_GPIO_Init(GPIOB, &GPIO_InitStruct);
}

/**
 * Shutdown is used to enter stop mode in a clean state.  This ensures that
 * all IP have been reset & re-initialized to their default state when
 * entering low-power stop mode.  This is a work-around until we can
 * determine what causes a high-discharge state after USB is enabled.
 *
 * @param argument is unused.
 */
void shutdown(void const * argument)
{
    UNUSED(argument);
    stop_now = 1;
    HAL_NVIC_SystemReset();
}

/*
 * Same algorithm as here: https://github.com/libopencm3/libopencm3/blob/master/lib/stm32/desig.c
 */
void encode_serial_number()
{
    uint8_t *uid = (uint8_t *)UID_BASE;

    uint8_t serial[6];
    serial[0] = uid[11];
    serial[1] = uid[10] + uid[2];
    serial[2] = uid[9];
    serial[3] = uid[8] + uid[0];
    serial[4] = uid[7];
    serial[5] = uid[6];

    snprintf(
        serial_number_64,
        sizeof(serial_number_64),
        "%02X%02X%02X%02X%02X%02X",
        serial[0], serial[1], serial[2],
        serial[3], serial[4], serial[5]
    );
}

/* USER CODE END 0 */

/**
  * @brief  The application entry point.
  *
  * @retval None
  */
int main(void)
{
  /* USER CODE BEGIN 1 */
  // If not a software reset, reset the flags.  This prevents odd behavior
  // during initial power on and hardware resets where SRAM2 may be in an
  // inconsistent state.  During a soft reset, it should be initialized.
  if (!(RCC->CSR & RCC_CSR_SFTRSTF)) {
      go_back_to_sleep = 0;
      stop_now = 0;
      usb_wake_state = 0;
  }
  if (RCC->CSR & (RCC_CSR_PINRSTF|RCC_CSR_BORRSTF)) {
      reset_button = 1;
  } else {
      reset_button = 0;
  }
  __HAL_RCC_CLEAR_RESET_FLAGS();
  /* USER CODE END 1 */

  /* MCU Configuration----------------------------------------------------------*/

  /* Reset of all peripherals, Initializes the Flash interface and the Systick. */
  HAL_Init();

  /* Configure the system clock */
  SystemClock_Config();

  /* USER CODE BEGIN SysInit */
#ifdef KISS_LOGGING
  printf("start\r\n");
  if (error_message[0] != 0) {
      printf(error_message);
      error_message[0] = 0;
  }
#endif

  // Note that it is important that all GPIO interrupts are disabled until
  // the FreeRTOS kernel has started.  All GPIO interrupts  send messages
  // to the ioEventTask thread.  Attempts to use any message queues before
  // FreeRTOS has started will lead to problems.  Because of this, these
  // interrupts are enabled only when the ioEventTask thread starts.

  /* USER CODE END SysInit */

  /* Initialize all configured peripherals */
  MX_GPIO_Init();
  MX_DMA_Init();
  MX_RTC_Init();
  MX_USART3_UART_Init();
  MX_DAC1_Init();
  MX_ADC1_Init();
  MX_CRC_Init();
  MX_I2C1_Init();
  MX_TIM6_Init();
  MX_TIM7_Init();
  MX_RNG_Init();

  MX_OPAMP1_Init();
  /* USER CODE BEGIN 2 */
  if (stop_now) stop2();

  MX_TIM1_Init();           // Initialize the LED PWM timer and GPIOs.
  SCB->SHCSR |= 0x70000;    // Enable fault handlers;
  if (!go_back_to_sleep) {
      indicate_turning_on();    // LEDs on during boot.
#ifndef TNC3L
      if (HAL_GPIO_ReadPin(SW_POWER_GPIO_Port, SW_POWER_Pin) && reset_button) {
          reset_requested = 1;
      }
#endif

#ifdef TNC3L
      if (reset_button)
      {
          reset_requested = 1;
      }
#endif

  }

  encode_serial_number();

  // Manchester encoding mode on SWO.
  // *((volatile unsigned *)(TPI->SPPR)) = 0x00000001;


  if (!go_back_to_sleep) {
      // The Bluetooth module is powered on during MX_GPIO_Init().  BT_CMD
      // has a weak pull-up on the BT module and is in OD mode.  Pull the
      // pin low during boot to enter Bluetooth programming mode.  Here the
      // BT_CMD pin is switched to input mode to detect the state.  The
      // TNC must be reset to exit programming mode.

      // Wait for BT module to settle.
      GPIO_InitTypeDef GPIO_InitStructure;

      GPIO_InitStructure.Pin = BT_CMD_Pin;
      GPIO_InitStructure.Mode = GPIO_MODE_INPUT;
      GPIO_InitStructure.Pull = GPIO_PULLUP;
      HAL_GPIO_Init(BT_CMD_GPIO_Port, &GPIO_InitStructure);
      HAL_Delay(10);

      if (HAL_GPIO_ReadPin(BT_CMD_GPIO_Port, BT_CMD_Pin) == GPIO_PIN_RESET) {
          // Special test mode for programming the Bluetooth module.  The TNC
          // has the BT_CMD pin actively being pulled low.  In this case we
          // power on the BT module with BT_CMD held low and wait here without
          // initializing the UART.  We only exit via reset.
          HAL_UART_MspDeInit(&huart3);

          HAL_GPIO_WritePin(BT_RESET_GPIO_Port, BT_RESET_Pin, GPIO_PIN_RESET);
          HAL_Delay(1);
          HAL_GPIO_WritePin(BT_RESET_GPIO_Port, BT_RESET_Pin, GPIO_PIN_SET);
          HAL_Delay(200);

          printf("Bluetooth programming mode\r\n");

          while (1);
      }

      // Not in BT programming mode.  Switch BT_CMD back to OD mode.
      HAL_GPIO_WritePin(BT_CMD_GPIO_Port, BT_CMD_Pin, GPIO_PIN_SET);
      GPIO_InitStructure.Pin = BT_CMD_Pin;
      GPIO_InitStructure.Mode = GPIO_MODE_OUTPUT_OD;
      GPIO_InitStructure.Pull = GPIO_PULLUP;
      HAL_GPIO_Init(BT_CMD_GPIO_Port, &GPIO_InitStructure);
  }

  /* USER CODE END 2 */

  /* USER CODE BEGIN RTOS_MUTEX */
  /* add mutexes, ... */
  osMutexDef(hardwareInitMutex);
  hardwareInitMutexHandle = osMutexCreate(osMutex(hardwareInitMutex));
  osMutexWait(hardwareInitMutexHandle, osWaitForever);

  /* USER CODE END RTOS_MUTEX */

  /* USER CODE BEGIN RTOS_SEMAPHORES */
  /* add semaphores, ... */
#pragma GCC diagnostic push
#pragma GCC diagnostic ignored "-Wwrite-strings"    // cmsis-os is not const-correct.
  /* USER CODE END RTOS_SEMAPHORES */


  /* Create the timer(s) */
  /* definition and creation of beaconTimer1 */
  osTimerStaticDef(beaconTimer1, beacon, &beaconTimer1ControlBlock);
  beaconTimer1Handle = osTimerCreate(osTimer(beaconTimer1), osTimerPeriodic, NULL);

  /* definition and creation of beaconTimer2 */
  osTimerStaticDef(beaconTimer2, beacon, &beaconTimer2ControlBlock);
  beaconTimer2Handle = osTimerCreate(osTimer(beaconTimer2), osTimerPeriodic, NULL);

  /* definition and creation of beaconTimer3 */
  osTimerStaticDef(beaconTimer3, beacon, &beaconTimer3ControlBlock);
  beaconTimer3Handle = osTimerCreate(osTimer(beaconTimer3), osTimerPeriodic, NULL);

  /* definition and creation of beaconTimer4 */
  osTimerStaticDef(beaconTimer4, beacon, &beaconTimer4ControlBlock);
  beaconTimer4Handle = osTimerCreate(osTimer(beaconTimer4), osTimerPeriodic, NULL);

  /* definition and creation of usbShutdownTimer */
  osTimerStaticDef(usbShutdownTimer, shutdown, &usbShutdownTimerControlBlock);
  usbShutdownTimerHandle = osTimerCreate(osTimer(usbShutdownTimer), osTimerOnce, NULL);

  /* USER CODE BEGIN RTOS_TIMERS */
  /* start timers, add new ones, ... */
  /* USER CODE END RTOS_TIMERS */

  /* Create the thread(s) */
  /* definition and creation of defaultTask */
  osThreadStaticDef(defaultTask, StartDefaultTask, osPriorityIdle, 0, 256, defaultTaskBuffer, &defaultTaskControlBlock);
  defaultTaskHandle = osThreadCreate(osThread(defaultTask), NULL);

  /* definition and creation of ioEventTask */
  osThreadStaticDef(ioEventTask, startIOEventTask, osPriorityLow, 0, 384, ioEventTaskBuffer, &ioEventTaskControlBlock);
  ioEventTaskHandle = osThreadCreate(osThread(ioEventTask), NULL);

  /* definition and creation of audioInputTask */
  osThreadStaticDef(audioInputTask, startAudioInputTask, osPriorityAboveNormal, 0, 512, audioInputTaskBuffer, &audioInputTaskControlBlock);
  audioInputTaskHandle = osThreadCreate(osThread(audioInputTask), NULL);

  /* definition and creation of modulatorTask */
  osThreadStaticDef(modulatorTask, startModulatorTask, osPriorityAboveNormal, 0, 384, modulatorTaskBuffer, &modulatorTaskControlBlock);
  modulatorTaskHandle = osThreadCreate(osThread(modulatorTask), NULL);

  /* USER CODE BEGIN RTOS_THREADS */
  /* add threads, ... */
  /* USER CODE END RTOS_THREADS */

  /* Create the queue(s) */
  /* definition and creation of ioEventQueue */
  osMessageQStaticDef(ioEventQueue, 16, uint32_t, ioEventQueueBuffer, &ioEventQueueControlBlock);
  ioEventQueueHandle = osMessageCreate(osMessageQ(ioEventQueue), NULL);

  /* definition and creation of serialInputQueue */
  osMessageQStaticDef(serialInputQueue, 16, uint32_t, serialInputQueueBuffer, &serialInputQueueControlBlock);
  serialInputQueueHandle = osMessageCreate(osMessageQ(serialInputQueue), NULL);

  /* definition and creation of serialOutputQueue */
  osMessageQStaticDef(serialOutputQueue, 16, uint32_t, serialOutputQueueBuffer, &serialOutputQueueControlBlock);
  serialOutputQueueHandle = osMessageCreate(osMessageQ(serialOutputQueue), NULL);

  /* definition and creation of audioInputQueue */
  osMessageQStaticDef(audioInputQueue, 8, uint32_t, audioInputQueueBuffer, &audioInputQueueControlBlock);
  audioInputQueueHandle = osMessageCreate(osMessageQ(audioInputQueue), NULL);

  /* definition and creation of hdlcInputQueue */
  osMessageQStaticDef(hdlcInputQueue, 3, uint32_t, hdlcInputQueueBuffer, &hdlcInputQueueControlBlock);
  hdlcInputQueueHandle = osMessageCreate(osMessageQ(hdlcInputQueue), NULL);

  /* definition and creation of hdlcOutputQueue */
  osMessageQStaticDef(hdlcOutputQueue, 8, uint32_t, hdlcOutputQueueBuffer, &hdlcOutputQueueControlBlock);
  hdlcOutputQueueHandle = osMessageCreate(osMessageQ(hdlcOutputQueue), NULL);

  /* definition and creation of dacOutputQueue */
  osMessageQStaticDef(dacOutputQueue, 128, uint8_t, dacOutputQueueBuffer, &dacOutputQueueControlBlock);
  dacOutputQueueHandle = osMessageCreate(osMessageQ(dacOutputQueue), NULL);

  /* definition and creation of adcInputQueue */
  osMessageQStaticDef(adcInputQueue, 8, uint32_t, adcInputQueueBuffer, &adcInputQueueControlBlock);
  adcInputQueueHandle = osMessageCreate(osMessageQ(adcInputQueue), NULL);

  /* USER CODE BEGIN RTOS_QUEUES */
  /* add queues, ... */
#pragma GCC diagnostic pop

  // Initialize the DC offset DAC and the PGA op amp.  Calibrate the ADC.
  if (HAL_DAC_SetValue(&hdac1, DAC_CHANNEL_2, DAC_ALIGN_12B_R, 1024) != HAL_OK) Error_Handler();
  if (HAL_DAC_Start(&hdac1, DAC_CHANNEL_2) != HAL_OK) Error_Handler();
  if (HAL_OPAMP_SelfCalibrate(&hopamp1) != HAL_OK) Error_Handler();
  if (HAL_OPAMP_Start(&hopamp1) != HAL_OK) Error_Handler();
  if (HAL_ADCEx_Calibration_Start(&hadc1, ADC_SINGLE_ENDED) != HAL_OK) Error_Handler();

  if (!go_back_to_sleep) {

      // Initialize the BM78 Bluetooth module and the RTC date/time the first time we boot.
      if (!bm78_initialized() || reset_requested) {
          bm78_initialize();
          memset(error_message, 0, sizeof(error_message));
          // init_rtc_date_time();
      } else if (reset_button) {
          bm78_initialize_mac_address();
      }
      else bm78_wait_until_ready();
  }

  init_ioport();
  initCDC();
  initSerial();

  // Initialize option bytes.
  FLASH_OBProgramInitTypeDef obInit = {0};
  HAL_FLASHEx_OBGetConfig(&obInit);

  if ((obInit.OptionType & OPTIONBYTE_USER) == RESET) {
    printf("FAIL: option byte init\r\n");
    Error_Handler();
  }

#if 1
  // Do not erase SRAM2 during reset.
  if ((obInit.USERConfig & FLASH_OPTR_SRAM2_RST) == RESET) {
    obInit.OptionType = OPTIONBYTE_USER;
    obInit.USERType = OB_USER_SRAM2_RST;
    obInit.USERConfig = FLASH_OPTR_SRAM2_RST;
    HAL_FLASH_OB_Unlock();
    HAL_FLASHEx_OBProgram(&obInit);
    HAL_FLASH_OB_Lock();
    HAL_FLASH_OB_Launch();
  }
#endif

#if 1
  // Enable hardware parity check on SRAM2
  if ((obInit.USERConfig & FLASH_OPTR_SRAM2_PE) == RESET) {
    obInit.OptionType = OPTIONBYTE_USER;
    obInit.USERType = OB_USER_SRAM2_PE;
    obInit.USERConfig = FLASH_OPTR_SRAM2_PE;
    HAL_FLASH_OB_Unlock();
    HAL_FLASHEx_OBProgram(&obInit);
    HAL_FLASH_OB_Lock();
    HAL_FLASH_OB_Launch();
  }
#endif

//  MX_IWDG_Init();

  /* USER CODE END RTOS_QUEUES */
 

  /* Start scheduler */
  osKernelStart();
  
  /* We should never get here as control is now taken by the scheduler */

  /* Infinite loop */
  /* USER CODE BEGIN WHILE */
  while (1)
  {

  /* USER CODE END WHILE */

  /* USER CODE BEGIN 3 */

  }
  /* USER CODE END 3 */

}

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
/* USER CODE BEGIN 4 */
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

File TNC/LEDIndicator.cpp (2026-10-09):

// Copyright 2017-2021 Rob Riggs <rob@mobilinkd.com>
// All rights reserved.

#include "LEDIndicator.h"
#include "main.h"

#include <stm32l4xx_hal.h>
#include <stm32l4xx_hal_tim.h>
#include <stm32l4xx_hal_tim_ex.h>
#include <cmsis_os.h>

#include <functional>
#include <atomic>

#include <stdint.h>

extern TIM_HandleTypeDef LED_PWM_TIMER_HANDLE;

namespace mobilinkd {
namespace tnc {


/**
 * No connection shows a low, slow breathing. Each breath inhale takes
 * for 500ms, is held for 500ms, and exhaled in 500ms. This is repeated
 * every 10 seconds.  Maximum brightness is 20%.
 *
 * Each interrupt occurs at 10ms intervals.
 *
 * The sequence is:
 *  - ramp up 300ms(30)
 *  - hold 400ms (40)
 *  - ramp down 300ms (30)
 *  - wait 9000ms (900)
 *
 *
 */
struct NoConnection
{
    enum STATE
    {
        RAMP_UP_1, WAIT_1, RAMP_DN_1, WAIT_2
    };

    int count { 0 };
    int state { RAMP_UP_1 };

    int operator()()
    {
        int result;
        switch (state) {
        case RAMP_UP_1:
            result = count * 40;
#ifndef TNC3L
            if (count == 49)
            {
#endif
#ifdef TNC3L
            if (count >= 49)
            {
    #
#endif

                count = 0;
                state = WAIT_1;
            }
            else
            {
                ++count;
            }
            break;
        case WAIT_1:
            result = 2000;
#ifndef TNC3L
            if (count == 49)
#endif
#ifdef TNC3L
           	if(count>=49)
#endif
            {
                state = RAMP_DN_1;
                count = 49;
            }
            else
            {
                ++count;
            }
            break;
        case RAMP_DN_1:
            result = count * 40;
            if (count == 0)
            {
                count = 0;
                state = WAIT_2;
            }
            else
            {
                --count;
            }
            break;
        case WAIT_2:
            result = 0;
            if (count == 849)
            {
                state = RAMP_UP_1;
                count = 0;
            }
            else
            {
                ++count;
            }
            break;
        }
        return result;
    }
};

/**
 * Bluetooth connection shows a double blip. Each blip lasts for 200ms
 * and is separated by 200ms, and is repeated ever 5 seconds.
 *
 * Each interrupt occurs at 10ms intervals.
 *
 * The sequence is:
 *  - ramp up 100s(10)
 *  - ramp down 100ms (10)
 *  - wait 200ms (20)
 *  - ramp up 100ms (10)
 *  - ramp down 100ms (10)
 *  - wait 4400ms (440)
 *
 *
 */
struct BluetoothConnection
{
    enum STATE
    {
        RAMP_UP_1, RAMP_DN_1, WAIT_1, RAMP_UP_2, RAMP_DN_2, WAIT_2
    };

    int count { 0 };
    int pulse { 0 };
    int state { RAMP_UP_1 };
    int ramp[10] =
        { 1564, 3090, 4540, 5878, 7071, 8090, 8910, 9510, 9877, 9999 };

    int operator()()
    {
        int result;
        switch (state) {
        case RAMP_UP_1:
            result = ramp[count] / 2;
#ifndef TNC3L
            if (count == 9)
#endif
#ifdef TNC3L
            if (count >= 9)
#endif

            {
                state = RAMP_DN_1;
            }
            else
            {
                ++count;
            }
            break;
        case RAMP_DN_1:
            result = ramp[count] / 2;
            if (count == 0)
            {
                state = WAIT_1;
            }
            else
            {
                --count;
            }
            break;
        case WAIT_1:
            result = 0;
#ifndef TNC3L
            if (count == 19)
#endif
#ifdef TNC3L
            	if (count >= 19)
#endif

            {
                state = RAMP_UP_2;
                count = 0;
            }
            else
            {
                ++count;
            }
            break;
        case RAMP_UP_2:
            result = ramp[count] / 2;
#ifndef TNC3L
            if (count == 9)
#endif
#ifdef TNC3L
            if (count >= 9)
#endif

            {
                state = RAMP_DN_2;
            }
            else
            {
                ++count;
            }
            break;
        case RAMP_DN_2:
            result = ramp[count] / 2;
            if (count == 0)
            {
                state = WAIT_2;
            }
            else
            {
                --count;
            }
            break;
        case WAIT_2:
            result = 0;
            if (count == 439)
            {
                state = RAMP_UP_1;
                count = 0;
            }
            else
            {
                ++count;
            }
            break;
        }
        return result;
    }
};

/**
 * USB connection shows a triple blip. Each blip lasts for 200ms. The
 * first two are separated by 400ms.  The third comes 200ms later.  This
 * is repeated ever 5 seconds.
 *
 * Each interrupt occurs at 10ms intervals.
 *
 * The sequence is:
 *  - ramp up 100s(10)
 *  - ramp down 100ms (10)
 *  - wait 200ms (20)
 *  - ramp up 100s(10)
 *  - ramp down 100ms (10)
 *  - wait 400ms (20)
 *  - ramp up 100ms (10)
 *  - ramp down 100ms (10)
 *  - wait 3800ms (440)
 *
 *
 */
struct USBConnection
{
    enum STATE
    {
        RAMP_UP_1,
        RAMP_DN_1,
        WAIT_1,
        RAMP_UP_2,
        RAMP_DN_2,
        WAIT_2,
        RAMP_UP_3,
        RAMP_DN_3,
        WAIT_3
    };

    int count { 0 };
    int pulse { 0 };
    int state { RAMP_UP_1 };
    int ramp[10] =
        { 1564, 3090, 4540, 5878, 7071, 8090, 8910, 9510, 9877, 9999 };
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

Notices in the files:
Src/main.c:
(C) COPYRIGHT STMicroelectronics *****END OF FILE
